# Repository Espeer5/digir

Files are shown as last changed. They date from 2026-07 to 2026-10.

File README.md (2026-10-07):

# DigiR Mobile Digital Mode Transceiver

The DigiR project is an effort to build a fully open source embedded mobile digital mode transciever design for ham operators. Many digital modes tend to require taking a computer running ham software into the field to make connections, which I consider to be a limitation in comparison to analog modes. This project is designed to remove that hurdle by creating a fully embedded platform that enables mobile digital operations.

The full tool chain of the proejct will be open source, avoiding any costly software licenses or other tools out of reach of the average radio hobbyist. An exception to the open-soruce nature of the project are the STM32Cube software packages used for configuring and flashing the STM32 MCU, but these are free packages that are accessible to the hobbyist.

Please note that this project has been significantly delayed due to hardware availability and lead times, which have changed the scope of the project. In particular, the ECP5 development board is very hard to come by at the moment, which is changing the scope of the project. Resulting from this issue some work must now be done to design a custom ECP5 hardware module for development, aside from the eventual custom radio board, increasing both the time and expense required.

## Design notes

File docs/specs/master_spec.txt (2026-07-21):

###################################################################################################
#  DIGIR MASTER PROJECT SPEC
#
#  VERSION 0.1
###################################################################################################

This document defines the system-level requirements for the DigiR open-source amateur radio
platform.

###################################################################################################
#  CHANGE LOG
###################################################################################################

7/17/26  Edward Speer  Initial revision
7/18/26  Edward Speer  Add user control module & rename BPM

###################################################################################################
#  SYSTEM DESCRIPTION
###################################################################################################

DigiR is an open-source, modular digital transceiver designed for standalone mobile amateur radio
operation on digital modes. It consists of a reusable hardware design with extensible enbedded
software, which can be adapted to multiple modes of digital operation. The system is designed to
support education, experimentation, and genuine modern digital radio communications using open
development workflows.

Platform capabilities should include:
 - Self-contained HF digital transceiver operation
 - Mutliple digital communication modes
 - Battery-powered operation
 - Precise GNSS-disciplined timing
 - Open hardware interfaces
 - Open software interfaces
 - Field portability
 - Field firmware & FPGA upgrades 

###################################################################################################
#  TOP-LEVEL BLOCK DIAGRAM
###################################################################################################

                   ______________            ______________________________
                  |              |    5V    |                              |
                  | POWER MODULE |--------->| RF MODULE                    |
                  |              |          |   ___________     _________  |
                   --------------\   12V    |  |           |   |         | |
                         |        \---------|->| POWER AMP |-->| ANTENNA | |
                         | 5V         TX    |  |           |   |         | |
                         v       /--------->|   -----------     ---------  |
                   _____________/           /------------------------------
                  |             |     RX   /      
                  | BASEBAND    |<--------/  _____________________
                  | PROCESSING  |           |                     |
                  | MODULE      |<----------| USER CONTROL MODULE |
                  |             |    SPI    |                     |
                   -------------             ---------------------

###################################################################################################
# PERFORMANCE REQUIREMENTS
###################################################################################################

RF targets:
 - Full amateur general HF coverage (3-30MHz)
 - 96kHz+ ADC instantaneous bandwidth
 - 48kHz+ Usable processed bandwidth
 - 4+ Independently tunable DSP channels
 - 50Hz or less narrowest channels filter
 - 7dB or less receiver noise across supported bands
 - Blocking 60dB at 3kHz, 75dB at 25hHz
 - Minimum discernible signal (MDS) -125 dBm
 - Input damage threshold 10dB or higher
 - 10W+ TX output power

Frequency & Timing:
 - +/- 0.1ppm with GNSS locked
 - +/- 0.1ppm 10 minute holdover
 - +/- 0.5 ppm in freerun
 - Frequency tuning resolution 0.1Hz or less
 - 1us TOD offset, 1ms in holdover
 - 100us TX schedule error, 1ms in holdover

Power Consumption:
 - RX 15W, TX at 30-50W
 - Maximum transient draw: 65W

Required Modes (initial prototype):
 - FT8
 - APRS

###################################################################################################
#  HARDWARE DESCRIPTION
###################################################################################################

The hardware will consist of 3 modules which are connected across clearly documented electrical and
mechanical interfaces. Each module will have its own revision identifier and documentation. The
modules are:
1) Power Module: Responsible for safely charging and discharging the battery and providing properly
                 regulated power to all subsystems.

2) Baseband Processing Module: Resonsible for all messaging logic and the encoding/decoding of
                               symbols to RF.

3) User Control Module: Control surface for users to provide input and configuration, as well as
                        monitor status and operation.

4) RF Module: Responsible for operating the antenna to transmit and receive
              signals over the air.

### POWER MODULE ###

The role of the power module is to provide clean and regulated power to the device. It will support
3 classes of inputs:
1: Internal battery
2: External DC input
3: Charging input

The power module needs to support the following output modes:
1: Baseband processing module regulated supply at 5V, 20W max allocation
2: RF auxiliary supply at 5V, 7.5W max allocation
3: Power amplifier supply at 13.8V, 40W allocation

The power module operates as a state machine with the following states available:
 - Mechanical off/battery disconnect
 - Shipping state (electrically disconnected)
 - Standby
 - EncDec powered only
 - Rx enabled
 - Tx ready
 - Tx active
 - Charging
 - Fault shutdown (E-stop)

The power amplifier supply should be shutoff (reversion to Rx enabled state) when any fault
condition is triggered.

The power module needs to expose status data to the user input module for user monitoring. The
minimum set is:
 - Battery voltage
 - Battery current
 - Ext input voltage
 - Ext input current
 - Rail voltages and currents
 - Battery temperature
 - Charge status
 - Fault state

### BASEBAND PROCESSING MODULE ###

The role of the baseband processing module (BPM) is to provide protocol intelligence, DSP, timing,
logging, and host capabilities. It is the logical brain of the device. There are several subsystems
included.

 ________________________________________________________________________
|                                                    |                   | 
| BASEBAND PROCESSING MODULE                         |                   |
|  __________________                                |                   |
| |                  |                               |                   |
| | DATA CONVERSION  |                               |                   |
| |  _____   _____   |                               |                   |
| | | ADC | | DAC |  |                               |                   |
| |  -----   -----   |                               |                   |
|  ------------------                                |                   |
|  ^^^^^^^^^^^^^^^^^^                                |                   |
|  ||||||||||||||||||                                |                   |
|  vvvvvvvvvvvvvvvvvv                                |                   |
|  __________________     _________________________  |                   |
| |                  |<->|                         | |                   |
| |    PROCESSING    |<->| MEMORY/STORAGE          | |     Protocol      | 
| |  ______   _____  |<->|  _____   _____   _____  | |    Interfaces     |
| | | FPGA | | MCU | |<->| | VOL | | NVM | | USR | | |                   |
| |  ------   -----  |<->|  -----   -----   -----  | |                   |
|  ------------------     -------------------------  |                   |
|  ^^^^^^^^^^^^^^^^^^                                |                   |
|  ||||||||||||||||||                                |                   | 
|  vvvvvvvvvvvvvvvvvv                                |                   |
|  __________________                                |                   |
| |                  |                               |                   |
| | CLOCKS & TIMING  |                               |                   |
| |     ________     |                               |                   |
| |    | VCTCXO |    |                               |                   |
| |     --------     |                               |                   |
| |  ______   _____  |                               |                   |
| | | GNSS | | GEN | |                               |                   |
| |  ------   -----  |                               |                   |
|  ------------------                                |                   |
 ------------------------------------------------------------------------

The NVM holds the bootloader, primary firmware image, and FPGA configuration image, while the
volatile memory is used for runtime data. Some partition of memory is exposed for user data.
Detailed descriptions of each subsystem in the BPM can be found in the detailed docs for the
BPM module.

### USER CONTROL MODULE ###

The user input module consists of the following components, whose functionality is mode dependent
and configurable.
 - Touchscreen: provides display including status & waterfall, and controls including keypad & mode
                selection.
 - PTT switch: available for any phone modes, though the additional target modes do not include
               phone operation.
 - Power Switch
 - 3 rotary knobs: adopt different functions dependent on mode of operation. 

Other than the power switch which is directly in series with the power unit, the other controls
control the baseband processing unit through SPI to the MCU.

### RF MODULE ###

The RF module is composed of a concrete set of components, and is designed to be hot swappable
depending on the desired operating constraints. Components include:
 - Receiver
 - Transmit exciter
 - Power amplifier
 - Frequency synthesis
 - Band filtering
 - T/R switching
 - Measurement
 - Protection
 - Control & telemetry

###################################################################################################
#  SOFTWARE DESCRIPTION
###################################################################################################

The software architecture is both vertically and horizontally divided - horizontally between the
FPGA and the MCU, and vertically up the stack from driver to application level. The vertical layers
are:
1: Device Drivers
2: Hardware Services
3: DSP Services
4: Protocol Layer
5: Application Layer

Differentiated revision identifiers are distributed horizontally, to the FPGA and firmware
separately. 

### FPGA RESPONSIBILITIES ###

 - Streaming DSP
 - Filtering
 - FFT
 - Sample buffering
 - Time recovery
 - Hardware sync
 - DMA support

### FIRMWARE RESPONSIBILITIES ###

 - Radio control
 - Scheduling
 - User interface
 - Communications
 - Protocol implementation
 - Calibration
 - System health monitoring

Protocol implementations will be fully modular and use a standardized interface with the rest of
the system. 

### HOST SOFTWARE RESPONSIBILITIES ###

A number of host software capabilities must be provided to enable hacking on the platform:
 - Firmware updates
 - FPGA programming
 - Diagnostics & logging
 - Factory test
 - Development utils

The software project should have cross-architecture support and not require any proprietary
licensed software.

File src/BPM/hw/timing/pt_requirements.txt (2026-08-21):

###################################################################################################
#  DIGIR BPM CLOCK EVB REQUIREMENTS
#
#  VERSION 0.1
###################################################################################################

The clock EVB is going to be used for protoyping the timing subsystem of the baseband processing
module. Coupled with the MCU, FPGA, and GNSS module, it should constitute a fully GNSS disciplined
clock.

###################################################################################################
#  CHANGE LOG
###################################################################################################

8/15/26  Edward Speer  Initial revision

###################################################################################################
#  INPUTS
###################################################################################################

 - 3V3 external power input
 - System GND
 - Optional ref CLK in (bypasses onboard VCXO)

###################################################################################################
#  OUTPUTS
###################################################################################################

 - Raw VCXO output
 - 2 SMA clocks out from Si5351
 - 1 clock output on a header from Si5351
 - Tuning voltage test point
 - CLKIN test point (differs from VCXO out in bypass mode)
 - Plain 3V3 test point
 - Output clock test points

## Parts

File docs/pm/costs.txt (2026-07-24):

###################################################################################################
#  DIGIR COSTS
###################################################################################################

This document describes all costs curred during the completion of the DigiR project, including test
equipment, licensing, etc. Not all of these costs are necessary for simply building the finished
product, and your mileage may vary. Items are marked with category and whether or not they're
required for the minimal build. 
 _________________________________________________________________________________________________
| ITEM | COST | CATEGORY  | REQUIRED? | SOURCE |
|---|---|---|---|---|
| FCC amateur license | $49 | Licensing | yes | Local testing organization, FCC. |
|-------------------------|---------|-----------|-----------|-------------------------------------|
| STM32H745I-DISCO | $154.78 | Bring up  | no | ST-direct |
|-------------------------|---------|-----------|-----------|-------------------------------------|
| KA3005P | $155.00 | Testing | no | Amazon |
|-------------------------|---------|-----------|-----------|-------------------------------------|
| ESD tweezers | $5.99 | Bench | no | Amazon |
|-------------------------|---------|-----------|-----------|-------------------------------------|
| ESD mat, bracelet | $20.99  | Bench | no | Amazon |
|-------------------------|---------|-----------|-----------|-------------------------------------|
| HiLetgo logic analyer | $12.69  | Test | no | Amazon |
|-------------------------------------------------------------------------------------------------|
| TOTAL: $358.78 |
|-------------------------------------------------------------------------------------------------|
| REQUIRED: $49 |
 -------------------------------------------------------------------------------------------------

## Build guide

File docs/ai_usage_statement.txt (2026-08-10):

###################################################################################################
#  DIGIR AI USAGE STATEMENT
#
#  VERSION 0.1
###################################################################################################

This document describes the ways in which AI has and has not been used in the completion of the
digiR project.

###################################################################################################
#  USAGE STATEMENT
###################################################################################################

Some of the primary objectives of this project include education and reproducability. AI can be an
extremely powerful tool for assisting these objectives, but only when interacted with in specific
ways. For example, asking an LLM to explain a certain concept or technical requirement can be much
more effective than a web search. The ability to ask follow-up questions in particular can replace
a lot of manual research and allow rapid learning. However, not all uses of AI achieve this goal -
in particular asking an agent to design a subsystem or write the code can bypass the learning
process altogether. It is of course, still possible to learn this way when time and care is taken
to understand the outputs, but I personally feel that I don't learn as well this way as I do in the
process of manually producing the components. For this reason I have developed a brief set of
guidelines that describe the guardrails I will apply to the use of AI in this project. When working
with this project, feel free to use AI however you like to your heart's content -- these are merely
my own guardrails to hold myself to in order to promote my own learning and objectives.

### GUARDRAILS ###

1: Chat mode only

One major point of emphasis for this project is that I learn best by doing, and I want to manually
write the code and create the schematics. For this reason I don't want to set agents loose into the
workspace to go and build things for me.

2: No debugging

AI is very good at debugging, but doing it manually is satisfying to me and helps me avoid making
repeat mistakes in the future. I also intend to work with some unfamiliar languages during the
course of the project and learning the syntax rather than asking an LLM to fix it is very valuable
for language mastery.

3: Always ask for sources

Not because I don't believe the AI outputs are accurate -- they typically are. Instead, I want to
know what sources should be consulted to find the answers to the questions I have. Also, I'm doing
this project because I'm interested in the project topic, and I suspect that the sources the LLM
cites will prove interesting enough to read through, providing additional learning.

4: Log interactions

It may be valuable or interesting for those following this project to see how AI has been used in
different phases of the project. After consulting with AI, record brief logs of how it was used and
what was learned in the process for transparency to others. Logs will be kept below in this
document.

###################################################################################################
#  USAGE LOGS
###################################################################################################
 _________________________________________________________________________________________________
| DATE | MODEL | USE CASE | NOTES |
|---|---|---|---|
| 07/18/26 | GPT 5.6 | Technical specs for RF module | Primary source cited and used for spec dev |
| | | to support digital modes | was the WSJT-X protocol specification. |
|----------|---------|-------------------------------|--------------------------------------------|
| 07/20/26 | GPT 5.6 | Scraping web for dev kits to  | Due to memory shortage everything is |
| | | purchase at reasonable prices | pricy, and AI didn't really help. |
|----------|---------|-------------------------------|--------------------------------------------|
| 07/23/26 | GPT 5.6 | Use of open source tools for  | Pointed me directly to |
| | | synthesizing/flashing ECP5 | jjhorton.co.uk/posts/ecp5g-eval/ which |
| | | hardware. | provided all the answers I needed. |
|----------|---------|-------------------------------|--------------------------------------------|
| 07/24/26 | GPT 5.6 | Table-based testbench inSV. | Provided a great pattern, but it isn't |
| | | | supported by Icarus. Gave me a different |
| | | | way of doing it that I don't really like.  |
|----------|---------|-------------------------------|--------------------------------------------|
| 07/25/26 | GPT 5.6 | Discussion of general design  | Referred to generic documents about PI |
| | | of time servo. | control that were too basic, but provided  |
| | | | useful guidance on fixed-point usage. |
|----------|---------|-------------------------------|--------------------------------------------|
| 07/27/26 | GPT 5.6 | Toolchain setup for STM32 FW  | Yes, I used it for some CMake debugging. |
| | | | Yes, that's slightly against the policy. |
| | | | But now everything builds and I'm happy. |
|----------|---------|-------------------------------|--------------------------------------------|
| 07/29/26 | GPT 5.6 | STM32 interrupt handlers | I didn't really want to dig through the |
| | | | generated code to see how to capture and |
| | | | handle UART interrupts. GPT was able to |
| | | | tell me where the code was easily. |
|----------|---------|-------------------------------|--------------------------------------------|
| 07/30/36 | GPT 5.5 | NMEA format/protocol | GPT pointed me to |
| | | | https://gpsd.gitlab.io/gpsd/NMEA.html |
|----------|---------|-------------------------------|--------------------------------------------|
| 07/31/26 | GPT 5.6 | Syntax for writing to UART3 | Yeah I could've check the HAL docs but how |
| | | | much would that really have taught me? |
|----------|---------|-------------------------------|--------------------------------------------|
| 08/02/26 | GPT 5.6 | Use of PulseView for logic | Needed instructions on which model to |
| | | analyzer model. | select in the menu since my analyzer is |
| | | | unmarked. |
|----------|---------|-------------------------------|--------------------------------------------|
| 08/10/26 | GPT 5.6 | Functional gaps with HW NSS | STM32 HW NSS usage is apparently very |
| | | | limiting to what you can do with your FPGA |
| | | | on the other side. Glad GPT warned me. |
 -------------------------------------------------------------------------------------------------

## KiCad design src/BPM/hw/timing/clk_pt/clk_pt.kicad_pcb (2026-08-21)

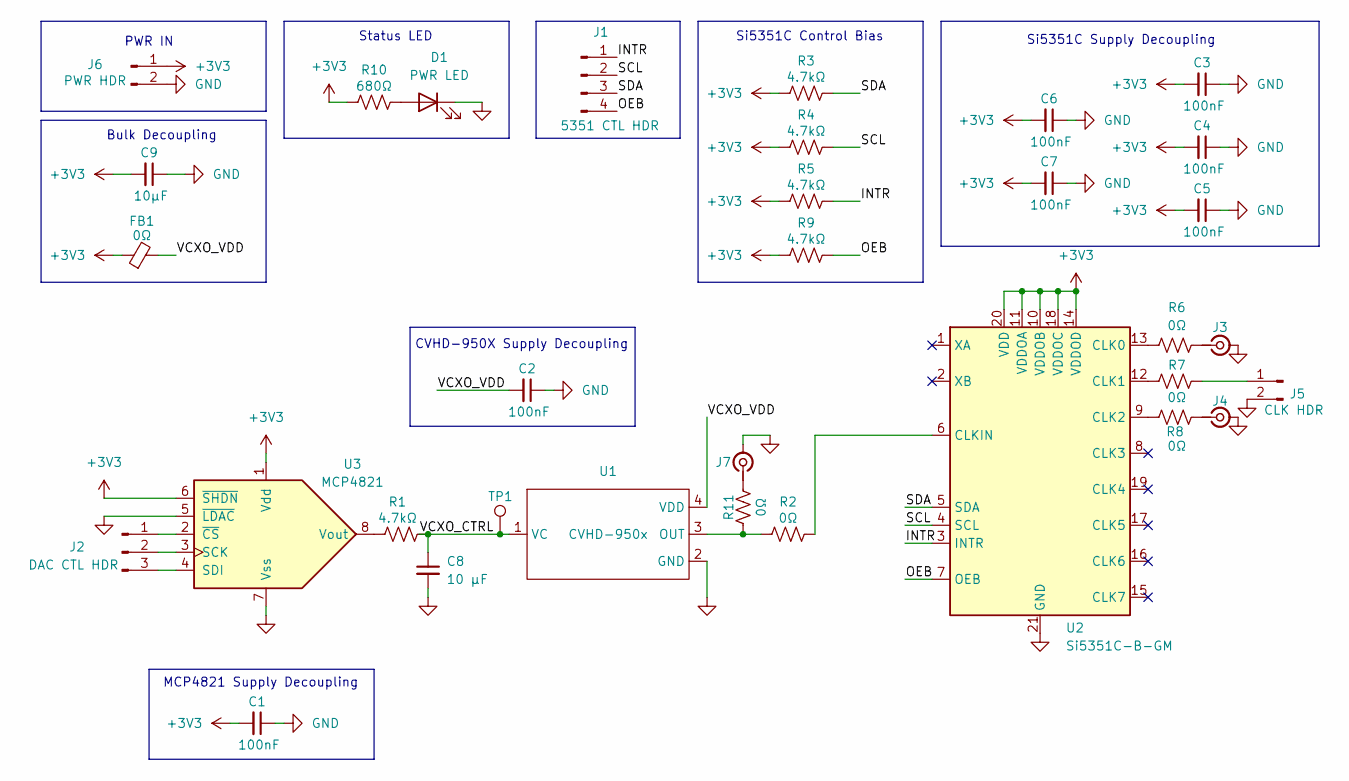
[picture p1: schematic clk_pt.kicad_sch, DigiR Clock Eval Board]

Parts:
C1, C2, C3, C4, C5, C6, C7: 100nF; C_0603_1608Metric
C8: 10 µF; C_0805_2012Metric
C9: 10µF; C_0805_2012Metric
D1: PWR LED; LED_0805_2012Metric
FB1: 0Ω; R_0603_1608Metric
J1: 5351 CTL HDR; PinHeader_1x04_P2.54mm_Vertical
J2: DAC CTL HDR; PinHeader_1x03_P2.54mm_Vertical
J3, J4, J7: SMA_Molex_73251-1153_EdgeMount_Horizontal
J5: CLK HDR; PinHeader_1x02_P2.54mm_Vertical
J6: PWR HDR; PinHeader_1x02_P2.54mm_Vertical
R1, R3, R4, R5, R9: 4.7kΩ; R_0603_1608Metric
R2, R6, R7, R8, R11: 0Ω; R_0603_1608Metric
R10: 680Ω; R_0603_1608Metric
TP1: TestPoint; TestPoint_THTPad_D2.0mm_Drill1.0mm
U1: CVHD-950x; OSC_CVHD-950X-100
U2: Si5351C-B-GM; QFN-20-1EP_4x4mm_P0.5mm_EP2.7x2.7mm
U3: MCP4821; SOIC-8_3.9x4.9mm_P1.27mm

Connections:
+3V3: C1.2, C3.2, C4.2, C5.2, C6.2, C7.2, C9.2, FB1.1, J6.1, R3.1, R4.1, R5.1, R9.1, R10.1, U2.10 (VDDOB), U2.11 (VDDOA), U2.14 (VDDOD), U2.18 (VDDOC), U2.20 (VDD), U3.1 (Vdd), U3.6 (~SHDN)
/INTR: J1.1, R5.2, U2.3 (INTR)
/OEB: J1.4, R9.2, U2.7 (OEB)
/SCL: J1.2, R4.2, U2.4 (SCL)
/SDA: J1.3, R3.2, U2.5 (SDA)
/VCXO_CTRL: C8.1, R1.2, TP1.1 (1_1), U1.1 (VC)
/VCXO_VDD: C2.2, FB1.2, U1.4 (VDD)
GND: C1.1, C2.1, C3.1, C4.1, C5.1, C6.1, C7.1, C8.2, C9.1, D1.1 (K), J3.2 (Ext), J4.2 (Ext), J5.2, J6.2, J7.2 (Ext), U1.2 (GND), U2.21 (GND), U3.5 (~LDAC), U3.7 (Vss)
unnamed: D1.2 (A), R10.2
unnamed: J2.1, U3.2 (~CS)
unnamed: J2.2, U3.3 (SCK)
unnamed: J2.3, U3.4 (SDI)
unnamed: J3.1 (In), R6.2
unnamed: J4.1 (In), R8.2
unnamed: J5.1, R7.2
unnamed: J7.1 (In), R11.2
unnamed: R2.1, R11.1, U1.3 (OUT)
unnamed: R6.1, U2.13 (CLK0)
unnamed: R7.1, U2.12 (CLK1)
unnamed: R8.1, U2.9 (CLK2)
unnamed: R2.2, U2.6 (CLKIN)
unnamed: R1.1, U3.8 (Vout)

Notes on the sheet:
CVHD-950X Supply Decoupling
Status LED
Si5351C Supply Decoupling
Bulk Decoupling
MCP4821 Supply Decoupling
Si5351C Control Bias
PWR IN

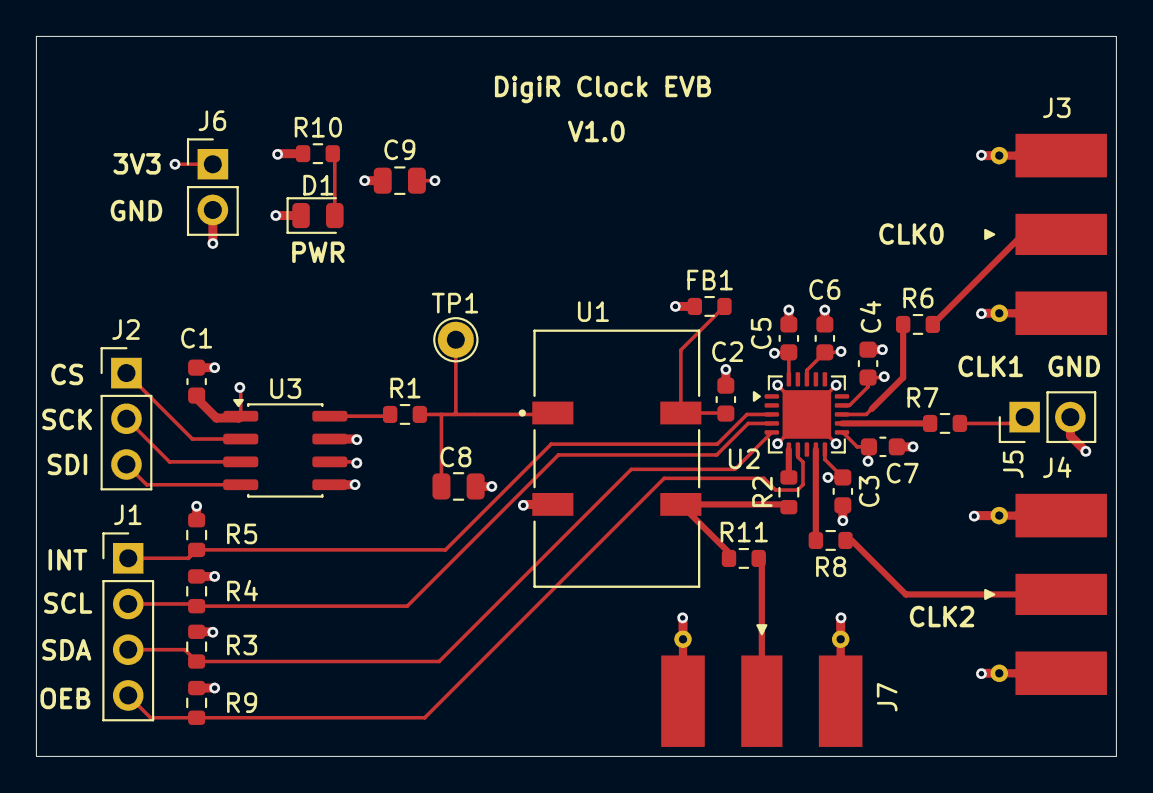
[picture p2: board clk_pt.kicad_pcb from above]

Board: 4 copper layers, 60.0 x 40.0 mm, 33 parts (0 on the bottom side), 22 nets.

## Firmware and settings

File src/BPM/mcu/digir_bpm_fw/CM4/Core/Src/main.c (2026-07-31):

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
/* Includes ------------------------------------------------------------------*/
#include "main.h"
#include "string.h"

/* USER CODE BEGIN PD */

/* DUAL_CORE_BOOT_SYNC_SEQUENCE: Define for dual core boot synchronization    */
/*                             demonstration code based on hardware semaphore */
/* This define is present in both CM7/CM4 projects                            */
/* To comment when developping/debugging on a single core                     */
#define DUAL_CORE_BOOT_SYNC_SEQUENCE

#if defined(DUAL_CORE_BOOT_SYNC_SEQUENCE)
#ifndef HSEM_ID_0
#define HSEM_ID_0 (0U) /* HW semaphore 0*/
#endif
#endif /* DUAL_CORE_BOOT_SYNC_SEQUENCE */

/* USER CODE END PD */

#if defined ( __ICCARM__ ) /*!< IAR Compiler */
#pragma location=0x10040000
ETH_DMADescTypeDef  DMARxDscrTab[ETH_RX_DESC_CNT]; /* Ethernet Rx DMA Descriptors */
#pragma location=0x10040080
ETH_DMADescTypeDef  DMATxDscrTab[ETH_TX_DESC_CNT]; /* Ethernet Tx DMA Descriptors */

#elif defined ( __CC_ARM )  /* MDK ARM Compiler */

__attribute__((at(0x10040000))) ETH_DMADescTypeDef  DMARxDscrTab[ETH_RX_DESC_CNT]; /* Ethernet Rx DMA Descriptors */
__attribute__((at(0x10040080))) ETH_DMADescTypeDef  DMATxDscrTab[ETH_TX_DESC_CNT]; /* Ethernet Tx DMA Descriptors */

#elif defined ( __GNUC__ ) /* GNU Compiler */

ETH_DMADescTypeDef DMARxDscrTab[ETH_RX_DESC_CNT] __attribute__((section(".RxDescripSection"))); /* Ethernet Rx DMA Descriptors */
ETH_DMADescTypeDef DMATxDscrTab[ETH_TX_DESC_CNT] __attribute__((section(".TxDescripSection")));   /* Ethernet Tx DMA Descriptors */
#endif

ETH_TxPacketConfig TxConfig;

ETH_HandleTypeDef heth;

FDCAN_HandleTypeDef hfdcan1;
FDCAN_HandleTypeDef hfdcan2;

LTDC_HandleTypeDef hltdc;

QSPI_HandleTypeDef hqspi;

SAI_HandleTypeDef hsai_BlockA2;
SAI_HandleTypeDef hsai_BlockB2;

MMC_HandleTypeDef hmmc1;

PCD_HandleTypeDef hpcd_USB_OTG_FS;

SDRAM_HandleTypeDef hsdram1;

static void MX_GPIO_Init(void);
static void MX_ETH_Init(void);
static void MX_FDCAN1_Init(void);
static void MX_FDCAN2_Init(void);
static void MX_FMC_Init(void);
static void MX_LTDC_Init(void);
static void MX_QUADSPI_Init(void);
static void MX_SAI2_Init(void);
static void MX_SDMMC1_MMC_Init(void);
static void MX_USB_OTG_FS_PCD_Init(void);
/**
  * @brief  The application entry point.
  * @retval int
  */
int main(void)
{

/* USER CODE BEGIN Boot_Mode_Sequence_1 */
#if defined(DUAL_CORE_BOOT_SYNC_SEQUENCE)
  /*HW semaphore Clock enable*/
  __HAL_RCC_HSEM_CLK_ENABLE();
  /* Activate HSEM notification for Cortex-M4*/
  HAL_HSEM_ActivateNotification(__HAL_HSEM_SEMID_TO_MASK(HSEM_ID_0));
  /*
  Domain D2 goes to STOP mode (Cortex-M4 in deep-sleep) waiting for Cortex-M7 to
  perform system initialization (system clock config, external memory configuration.. )
  */
  HAL_PWREx_ClearPendingEvent();
  HAL_PWREx_EnterSTOPMode(PWR_MAINREGULATOR_ON, PWR_STOPENTRY_WFE, PWR_D2_DOMAIN);
  /* Clear HSEM flag */
  __HAL_HSEM_CLEAR_FLAG(__HAL_HSEM_SEMID_TO_MASK(HSEM_ID_0));

#endif /* DUAL_CORE_BOOT_SYNC_SEQUENCE */
/* USER CODE END Boot_Mode_Sequence_1 */
  /* MCU Configuration--------------------------------------------------------*/

  /* Reset of all peripherals, Initializes the Flash interface and the Systick. */
  HAL_Init();

  /* Initialize all configured peripherals */
  MX_GPIO_Init();
  MX_ETH_Init();
  MX_FDCAN1_Init();
  MX_FDCAN2_Init();
  MX_FMC_Init();
  MX_LTDC_Init();
  MX_QUADSPI_Init();
  MX_SAI2_Init();
  MX_SDMMC1_MMC_Init();
  MX_USB_OTG_FS_PCD_Init();
  /* Infinite loop */
  /* USER CODE BEGIN WHILE */
  while (1)
  {
    /* USER CODE END WHILE */

    /* USER CODE BEGIN 3 */
  }
  /* USER CODE END 3 */
}

/**
  * @brief ETH Initialization Function
  * @param None
  * @retval None
  */
static void MX_ETH_Init(void)
{

   static uint8_t MACAddr[6];

  heth.Instance = ETH;
  MACAddr[0] = 0x00;
  MACAddr[1] = 0x80;
  MACAddr[2] = 0xE1;
  MACAddr[3] = 0x00;
  MACAddr[4] = 0x00;
  MACAddr[5] = 0x00;
  heth.Init.MACAddr = &MACAddr[0];
  heth.Init.MediaInterface = HAL_ETH_MII_MODE;
  heth.Init.TxDesc = DMATxDscrTab;
  heth.Init.RxDesc = DMARxDscrTab;
  heth.Init.RxBuffLen = 1536;

  if (HAL_ETH_Init(&heth) != HAL_OK)
  {
    Error_Handler();
  }

  memset(&TxConfig, 0 , sizeof(ETH_TxPacketConfig));
  TxConfig.Attributes = ETH_TX_PACKETS_FEATURES_CSUM | ETH_TX_PACKETS_FEATURES_CRCPAD;
  TxConfig.ChecksumCtrl = ETH_CHECKSUM_IPHDR_PAYLOAD_INSERT_PHDR_CALC;
  TxConfig.CRCPadCtrl = ETH_CRC_PAD_INSERT;
}

/**
  * @brief FDCAN1 Initialization Function
  * @param None
  * @retval None
  */
static void MX_FDCAN1_Init(void)
{

  hfdcan1.Instance = FDCAN1;
  hfdcan1.Init.FrameFormat = FDCAN_FRAME_CLASSIC;
  hfdcan1.Init.Mode = FDCAN_MODE_NORMAL;
  hfdcan1.Init.AutoRetransmission = DISABLE;
  hfdcan1.Init.TransmitPause = DISABLE;
  hfdcan1.Init.ProtocolException = DISABLE;
  hfdcan1.Init.NominalPrescaler = 16;
  hfdcan1.Init.NominalSyncJumpWidth = 1;
  hfdcan1.Init.NominalTimeSeg1 = 1;
  hfdcan1.Init.NominalTimeSeg2 = 1;
  hfdcan1.Init.DataPrescaler = 1;
  hfdcan1.Init.DataSyncJumpWidth = 1;
  hfdcan1.Init.DataTimeSeg1 = 1;
  hfdcan1.Init.DataTimeSeg2 = 1;
  hfdcan1.Init.MessageRAMOffset = 0;
  hfdcan1.Init.StdFiltersNbr = 0;
  hfdcan1.Init.ExtFiltersNbr = 0;
  hfdcan1.Init.RxFifo0ElmtsNbr = 0;
  hfdcan1.Init.RxFifo0ElmtSize = FDCAN_DATA_BYTES_8;
  hfdcan1.Init.RxFifo1ElmtsNbr = 0;
  hfdcan1.Init.RxFifo1ElmtSize = FDCAN_DATA_BYTES_8;
  hfdcan1.Init.RxBuffersNbr = 0;
  hfdcan1.Init.RxBufferSize = FDCAN_DATA_BYTES_8;
  hfdcan1.Init.TxEventsNbr = 0;
  hfdcan1.Init.TxBuffersNbr = 0;
  hfdcan1.Init.TxFifoQueueElmtsNbr = 0;
  hfdcan1.Init.TxFifoQueueMode = FDCAN_TX_FIFO_OPERATION;
  hfdcan1.Init.TxElmtSize = FDCAN_DATA_BYTES_8;
  if (HAL_FDCAN_Init(&hfdcan1) != HAL_OK)
  {
    Error_Handler();
  }
}

/**
  * @brief FDCAN2 Initialization Function
  * @param None
  * @retval None
  */
static void MX_FDCAN2_Init(void)
{

  hfdcan2.Instance = FDCAN2;
  hfdcan2.Init.FrameFormat = FDCAN_FRAME_CLASSIC;
  hfdcan2.Init.Mode = FDCAN_MODE_NORMAL;
  hfdcan2.Init.AutoRetransmission = DISABLE;
  hfdcan2.Init.TransmitPause = DISABLE;
  hfdcan2.Init.ProtocolException = DISABLE;
  hfdcan2.Init.NominalPrescaler = 16;
  hfdcan2.Init.NominalSyncJumpWidth = 1;
  hfdcan2.Init.NominalTimeSeg1 = 1;
  hfdcan2.Init.NominalTimeSeg2 = 1;
  hfdcan2.Init.DataPrescaler = 1;
  hfdcan2.Init.DataSyncJumpWidth = 1;
  hfdcan2.Init.DataTimeSeg1 = 1;
  hfdcan2.Init.DataTimeSeg2 = 1;
  hfdcan2.Init.MessageRAMOffset = 0;
  hfdcan2.Init.StdFiltersNbr = 0;
  hfdcan2.Init.ExtFiltersNbr = 0;
  hfdcan2.Init.RxFifo0ElmtsNbr = 0;
  hfdcan2.Init.RxFifo0ElmtSize = FDCAN_DATA_BYTES_8;
  hfdcan2.Init.RxFifo1ElmtsNbr = 0;
  hfdcan2.Init.RxFifo1ElmtSize = FDCAN_DATA_BYTES_8;
  hfdcan2.Init.RxBuffersNbr = 0;
  hfdcan2.Init.RxBufferSize = FDCAN_DATA_BYTES_8;
  hfdcan2.Init.TxEventsNbr = 0;
  hfdcan2.Init.TxBuffersNbr = 0;
  hfdcan2.Init.TxFifoQueueElmtsNbr = 0;
  hfdcan2.Init.TxFifoQueueMode = FDCAN_TX_FIFO_OPERATION;
  hfdcan2.Init.TxElmtSize = FDCAN_DATA_BYTES_8;
  if (HAL_FDCAN_Init(&hfdcan2) != HAL_OK)
  {
    Error_Handler();
  }
}

/**
  * @brief LTDC Initialization Function
  * @param None
  * @retval None
  */
static void MX_LTDC_Init(void)
{

  LTDC_LayerCfgTypeDef pLayerCfg = {0};
  LTDC_LayerCfgTypeDef pLayerCfg1 = {0};

  hltdc.Instance = LTDC;
  hltdc.Init.HSPolarity = LTDC_HSPOLARITY_AL;
  hltdc.Init.VSPolarity = LTDC_VSPOLARITY_AL;
  hltdc.Init.DEPolarity = LTDC_DEPOLARITY_AL;
  hltdc.Init.PCPolarity = LTDC_PCPOLARITY_IPC;
  hltdc.Init.HorizontalSync = 7;
  hltdc.Init.VerticalSync = 3;
  hltdc.Init.AccumulatedHBP = 14;
  hltdc.Init.AccumulatedVBP = 5;
  hltdc.Init.AccumulatedActiveW = 654;
  hltdc.Init.AccumulatedActiveH = 485;
  hltdc.Init.TotalWidth = 660;
  hltdc.Init.TotalHeigh = 487;
  hltdc.Init.Backcolor.Blue = 0;
  hltdc.Init.Backcolor.Green = 0;
  hltdc.Init.Backcolor.Red = 0;
  if (HAL_LTDC_Init(&hltdc) != HAL_OK)
  {
    Error_Handler();
  }
  pLayerCfg.WindowX0 = 0;
  pLayerCfg.WindowX1 = 0;
  pLayerCfg.WindowY0 = 0;
  pLayerCfg.WindowY1 = 0;
  pLayerCfg.PixelFormat = LTDC_PIXEL_FORMAT_ARGB8888;
  pLayerCfg.Alpha = 0;
  pLayerCfg.Alpha0 = 0;
  pLayerCfg.BlendingFactor1 = LTDC_BLENDING_FACTOR1_CA;
  pLayerCfg.BlendingFactor2 = LTDC_BLENDING_FACTOR2_CA;
  pLayerCfg.FBStartAdress = 0;
  pLayerCfg.ImageWidth = 0;
  pLayerCfg.ImageHeight = 0;
  pLayerCfg.Backcolor.Blue = 0;
  pLayerCfg.Backcolor.Green = 0;
  pLayerCfg.Backcolor.Red = 0;
  if (HAL_LTDC_ConfigLayer(&hltdc, &pLayerCfg, 0) != HAL_OK)
  {
    Error_Handler();
  }
  pLayerCfg1.WindowX0 = 0;
  pLayerCfg1.WindowX1 = 0;
  pLayerCfg1.WindowY0 = 0;
  pLayerCfg1.WindowY1 = 0;
  pLayerCfg1.PixelFormat = LTDC_PIXEL_FORMAT_ARGB8888;
  pLayerCfg1.Alpha = 0;
  pLayerCfg1.Alpha0 = 0;
  pLayerCfg1.BlendingFactor1 = LTDC_BLENDING_FACTOR1_CA;
  pLayerCfg1.BlendingFactor2 = LTDC_BLENDING_FACTOR2_CA;
  pLayerCfg1.FBStartAdress = 0;
  pLayerCfg1.ImageWidth = 0;
  pLayerCfg1.ImageHeight = 0;
  pLayerCfg1.Backcolor.Blue = 0;
  pLayerCfg1.Backcolor.Green = 0;
  pLayerCfg1.Backcolor.Red = 0;
  if (HAL_LTDC_ConfigLayer(&hltdc, &pLayerCfg1, 1) != HAL_OK)
  {
    Error_Handler();
  }
}

/**
  * @brief QUADSPI Initialization Function
  * @param None
  * @retval None
  */
static void MX_QUADSPI_Init(void)
{

  /* QUADSPI parameter configuration*/
  hqspi.Instance = QUADSPI;
  hqspi.Init.ClockPrescaler = 255;
  hqspi.Init.FifoThreshold = 1;
  hqspi.Init.SampleShifting = QSPI_SAMPLE_SHIFTING_NONE;
  hqspi.Init.FlashSize = 1;
  hqspi.Init.ChipSelectHighTime = QSPI_CS_HIGH_TIME_1_CYCLE;
  hqspi.Init.ClockMode = QSPI_CLOCK_MODE_0;
  hqspi.Init.FlashID = QSPI_FLASH_ID_1;
  hqspi.Init.DualFlash = QSPI_DUALFLASH_DISABLE;
  if (HAL_QSPI_Init(&hqspi) != HAL_OK)
  {
    Error_Handler();
  }
}

/**
  * @brief SAI2 Initialization Function
  * @param None
  * @retval None
  */
static void MX_SAI2_Init(void)
{

  hsai_BlockA2.Instance = SAI2_Block_A;
  hsai_BlockA2.Init.Protocol = SAI_FREE_PROTOCOL;
  hsai_BlockA2.Init.AudioMode = SAI_MODEMASTER_TX;
  hsai_BlockA2.Init.DataSize = SAI_DATASIZE_8;
  hsai_BlockA2.Init.FirstBit = SAI_FIRSTBIT_MSB;
  hsai_BlockA2.Init.ClockStrobing = SAI_CLOCKSTROBING_FALLINGEDGE;
  hsai_BlockA2.Init.Synchro = SAI_ASYNCHRONOUS;
  hsai_BlockA2.Init.OutputDrive = SAI_OUTPUTDRIVE_DISABLE;
  hsai_BlockA2.Init.NoDivider = SAI_MASTERDIVIDER_ENABLE;
  hsai_BlockA2.Init.MckOverSampling = SAI_MCK_OVERSAMPLING_DISABLE;
  hsai_BlockA2.Init.FIFOThreshold = SAI_FIFOTHRESHOLD_EMPTY;
  hsai_BlockA2.Init.AudioFrequency = SAI_AUDIO_FREQUENCY_192K;
  hsai_BlockA2.Init.SynchroExt = SAI_SYNCEXT_DISABLE;
  hsai_BlockA2.Init.MonoStereoMode = SAI_STEREOMODE;
  hsai_BlockA2.Init.CompandingMode = SAI_NOCOMPANDING;
  hsai_BlockA2.Init.TriState = SAI_OUTPUT_NOTRELEASED;
  hsai_BlockA2.Init.PdmInit.Activation = DISABLE;
  hsai_BlockA2.Init.PdmInit.MicPairsNbr = 1;
  hsai_BlockA2.Init.PdmInit.ClockEnable = SAI_PDM_CLOCK1_ENABLE;
  hsai_BlockA2.FrameInit.FrameLength = 8;
  hsai_BlockA2.FrameInit.ActiveFrameLength = 1;
  hsai_BlockA2.FrameInit.FSDefinition = SAI_FS_STARTFRAME;
  hsai_BlockA2.FrameInit.FSPolarity = SAI_FS_ACTIVE_LOW;
  hsai_BlockA2.FrameInit.FSOffset = SAI_FS_FIRSTBIT;
  hsai_BlockA2.SlotInit.FirstBitOffset = 0;
  hsai_BlockA2.SlotInit.SlotSize = SAI_SLOTSIZE_DATASIZE;
  hsai_BlockA2.SlotInit.SlotNumber = 1;
  hsai_BlockA2.SlotInit.SlotActive = 0x00000000;
  if (HAL_SAI_Init(&hsai_BlockA2) != HAL_OK)
  {
    Error_Handler();
  }
  hsai_BlockB2.Instance = SAI2_Block_B;
  hsai_BlockB2.Init.Protocol = SAI_FREE_PROTOCOL;
  hsai_BlockB2.Init.AudioMode = SAI_MODESLAVE_RX;
  hsai_BlockB2.Init.DataSize = SAI_DATASIZE_8;
  hsai_BlockB2.Init.FirstBit = SAI_FIRSTBIT_MSB;
  hsai_BlockB2.Init.ClockStrobing = SAI_CLOCKSTROBING_FALLINGEDGE;
  hsai_BlockB2.Init.Synchro = SAI_SYNCHRONOUS;
  hsai_BlockB2.Init.OutputDrive = SAI_OUTPUTDRIVE_DISABLE;
  hsai_BlockB2.Init.MckOverSampling = SAI_MCK_OVERSAMPLING_DISABLE;
  hsai_BlockB2.Init.FIFOThreshold = SAI_FIFOTHRESHOLD_EMPTY;
  hsai_BlockB2.Init.SynchroExt = SAI_SYNCEXT_DISABLE;
  hsai_BlockB2.Init.MonoStereoMode = SAI_STEREOMODE;
  hsai_BlockB2.Init.CompandingMode = SAI_NOCOMPANDING;
  hsai_BlockB2.Init.TriState = SAI_OUTPUT_NOTRELEASED;
  hsai_BlockB2.Init.PdmInit.Activation = DISABLE;
  hsai_BlockB2.Init.PdmInit.MicPairsNbr = 1;
  hsai_BlockB2.Init.PdmInit.ClockEnable = SAI_PDM_CLOCK1_ENABLE;
  hsai_BlockB2.FrameInit.FrameLength = 8;
  hsai_BlockB2.FrameInit.ActiveFrameLength = 1;
  hsai_BlockB2.FrameInit.FSDefinition = SAI_FS_STARTFRAME;
  hsai_BlockB2.FrameInit.FSPolarity = SAI_FS_ACTIVE_LOW;
  hsai_BlockB2.FrameInit.FSOffset = SAI_FS_FIRSTBIT;
  hsai_BlockB2.SlotInit.FirstBitOffset = 0;
  hsai_BlockB2.SlotInit.SlotSize = SAI_SLOTSIZE_DATASIZE;
  hsai_BlockB2.SlotInit.SlotNumber = 1;
  hsai_BlockB2.SlotInit.SlotActive = 0x00000000;
  if (HAL_SAI_Init(&hsai_BlockB2) != HAL_OK)
  {
    Error_Handler();
  }
}

/**
  * @brief SDMMC1 Initialization Function
  * @param None
  * @retval None
  */
static void MX_SDMMC1_MMC_Init(void)
{

  hmmc1.Instance = SDMMC1;
  hmmc1.Init.ClockEdge = SDMMC_CLOCK_EDGE_RISING;
  hmmc1.Init.ClockPowerSave = SDMMC_CLOCK_POWER_SAVE_DISABLE;
  hmmc1.Init.BusWide = SDMMC_BUS_WIDE_8B;
  hmmc1.Init.HardwareFlowControl = SDMMC_HARDWARE_FLOW_CONTROL_DISABLE;
  hmmc1.Init.ClockDiv = 0;
  if (HAL_MMC_Init(&hmmc1) != HAL_OK)
  {
    Error_Handler();
  }
}

/**
  * @brief USB_OTG_FS Initialization Function
  * @param None
  * @retval None
  */
static void MX_USB_OTG_FS_PCD_Init(void)
{

  hpcd_USB_OTG_FS.Instance = USB_OTG_FS;
  hpcd_USB_OTG_FS.Init.dev_endpoints = 9;
  hpcd_USB_OTG_FS.Init.speed = PCD_SPEED_FULL;
  hpcd_USB_OTG_FS.Init.dma_enable = DISABLE;
  hpcd_USB_OTG_FS.Init.phy_itface = PCD_PHY_EMBEDDED;
  hpcd_USB_OTG_FS.Init.Sof_enable = DISABLE;
  hpcd_USB_OTG_FS.Init.low_power_enable = DISABLE;
  hpcd_USB_OTG_FS.Init.lpm_enable = DISABLE;
  hpcd_USB_OTG_FS.Init.battery_charging_enable = ENABLE;
  hpcd_USB_OTG_FS.Init.vbus_sensing_enable = ENABLE;
  hpcd_USB_OTG_FS.Init.use_dedicated_ep1 = DISABLE;
  if (HAL_PCD_Init(&hpcd_USB_OTG_FS) != HAL_OK)
  {
    Error_Handler();
  }
}

/* FMC initialization function */
void MX_FMC_Init(void)
{

  FMC_SDRAM_TimingTypeDef SdramTiming = {0};

  /** Perform the SDRAM1 memory initialization sequence
  */
  hsdram1.Instance = FMC_SDRAM_DEVICE;
  /* hsdram1.Init */
  hsdram1.Init.SDBank = FMC_SDRAM_BANK2;
  hsdram1.Init.ColumnBitsNumber = FMC_SDRAM_COLUMN_BITS_NUM_8;
  hsdram1.Init.RowBitsNumber = FMC_SDRAM_ROW_BITS_NUM_12;
  hsdram1.Init.MemoryDataWidth = FMC_SDRAM_MEM_BUS_WIDTH_16;
  hsdram1.Init.InternalBankNumber = FMC_SDRAM_INTERN_BANKS_NUM_4;
  hsdram1.Init.CASLatency = FMC_SDRAM_CAS_LATENCY_1;
  hsdram1.Init.WriteProtection = FMC_SDRAM_WRITE_PROTECTION_DISABLE;
  hsdram1.Init.SDClockPeriod = FMC_SDRAM_CLOCK_DISABLE;
  hsdram1.Init.ReadBurst = FMC_SDRAM_RBURST_DISABLE;
  hsdram1.Init.ReadPipeDelay = FMC_SDRAM_RPIPE_DELAY_0;
  /* SdramTiming */
  SdramTiming.LoadToActiveDelay = 16;
  SdramTiming.ExitSelfRefreshDelay = 16;
  SdramTiming.SelfRefreshTime = 16;
  SdramTiming.RowCycleDelay = 16;
  SdramTiming.WriteRecoveryTime = 16;
  SdramTiming.RPDelay = 16;
  SdramTiming.RCDDelay = 16;

  if (HAL_SDRAM_Init(&hsdram1, &SdramTiming) != HAL_OK)
  {
    Error_Handler( );
  }

}

/**
  * @brief GPIO Initialization Function
  * @param None
  * @retval None
  */
static void MX_GPIO_Init(void)
{
  GPIO_InitTypeDef GPIO_InitStruct = {0};
  /* GPIO Ports Clock Enable */
  __HAL_RCC_GPIOI_CLK_ENABLE();
  __HAL_RCC_GPIOB_CLK_ENABLE();
  __HAL_RCC_GPIOK_CLK_ENABLE();
  __HAL_RCC_GPIOG_CLK_ENABLE();
  __HAL_RCC_GPIOC_CLK_ENABLE();
  __HAL_RCC_GPIOE_CLK_ENABLE();
  __HAL_RCC_GPIOJ_CLK_ENABLE();
  __HAL_RCC_GPIOH_CLK_ENABLE();
  __HAL_RCC_GPIOD_CLK_ENABLE();
  __HAL_RCC_GPIOA_CLK_ENABLE();
  __HAL_RCC_GPIOF_CLK_ENABLE();

  /*Configure GPIO pins : PE5 PE4 */
  GPIO_InitStruct.Pin = GPIO_PIN_5|GPIO_PIN_4;
  GPIO_InitStruct.Mode = GPIO_MODE_AF_PP;
  GPIO_InitStruct.Pull = GPIO_NOPULL;
  GPIO_InitStruct.Speed = GPIO_SPEED_FREQ_LOW;
  GPIO_InitStruct.Alternate = GPIO_AF10_SAI4;
  HAL_GPIO_Init(GPIOE, &GPIO_InitStruct);

}

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


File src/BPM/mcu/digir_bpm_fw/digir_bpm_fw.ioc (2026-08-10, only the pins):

Mcu.UserName=STM32H745XIHx
PA1.GPIO_Label=MII_RX_CLK
PA1.Signal=ETH_RX_CLK
PA10.GPIO_Label=USB_OTG_FS2_ID
PA10.Signal=GPIO_Input
PA11.GPIO_Label=USB_OTG_FS2_N
PA11.Signal=USB_OTG_FS_DM
PA12.GPIO_Label=USB_OTG_FS2_P
PA12.Signal=USB_OTG_FS_DP
PA2.GPIO_Label=MII_MDIO
PA2.Signal=ETH_MDIO
PA7.GPIO_Label=MII_RX_DV
PA7.Signal=ETH_RX_DV
PA9.GPIO_Label=VBUS_FS2
PA9.Signal=USB_OTG_FS_VBUS
PB0.GPIO_Label=MII_RXD2
PB0.Signal=ETH_RXD2
PB1.GPIO_Label=MII_RXD3
PB1.Signal=ETH_RXD3
PB10.GPIO_Label=VCP_TX
PB10.Signal=USART3_TX
PB11.GPIO_Label=VCP_RX
PB11.Signal=USART3_RX
PB12.GPIO_Label=LCD_RST
PB12.Signal=GPIO_Output
PB13.GPIO_Label=FDCAN2_TX
PB13.Signal=FDCAN2_TX
PB14.Signal=USART1_TX
PB15.Signal=SPI2_MOSI
PB5.GPIO_Label=FDCAN2_RX
PB5.Signal=FDCAN2_RX
PB6.Signal=QUADSPI_BK1_NCS
PB7.Signal=USART1_RX
PB8.GPIO_Label=SDIO1_D4
PB8.Signal=SDMMC1_D4
PB9.GPIO_Label=SDIO1_D5
PB9.Signal=SDMMC1_D5
PC1.GPIO_Label=MII_MDC
PC1.Signal=ETH_MDC
PC10.GPIO_Label=SDIO1_D2
PC10.Signal=SDMMC1_D2
PC11.GPIO_Label=SDIO1_D3
PC11.Signal=SDMMC1_D3
PC12.GPIO_Label=SDIO1_CK
PC12.Signal=SDMMC1_CK
PC13.GPIO_Label=B1 [Blue PushButton]
PC13.Signal=GPIO_Input
PC2.GPIO_Label=MII_TXD2
PC2.Signal=ETH_TXD2
PC3.GPIO_Label=MII_TX_CLK
PC3.Signal=ETH_TX_CLK
PC4.GPIO_Label=MII_RXD0
PC4.Signal=ETH_RXD0
PC5.GPIO_Label=MII_RXD1
PC5.Signal=ETH_RXD1
PC6.GPIO_Label=SDIO1_D6
PC6.Signal=SDMMC1_D6
PC7.GPIO_Label=SDIO1_D7
PC7.Signal=SDMMC1_D7
PC8.GPIO_Label=SDIO1_D0
PC8.Signal=SDMMC1_D0
PC9.GPIO_Label=SDIO1_D1
PC9.Signal=SDMMC1_D1
PD0.Signal=FMC_D2_DA2
PD1.Signal=FMC_D3_DA3
PD10.Signal=FMC_D15_DA15
PD11.Signal=QUADSPI_BK1_IO0
PD14.Signal=FMC_D0_DA0
PD15.Signal=FMC_D1_DA1
PD2.GPIO_Label=SDIO1_CMD
PD2.Signal=SDMMC1_CMD
PD3.Signal=SPI2_SCK
PD7.GPIO_Label=LCD_DISP
PD7.Signal=GPIO_Input
PD8.Signal=FMC_D13_DA13
PD9.Signal=FMC_D14_DA14
PE0.Signal=FMC_NBL0
PE1.Signal=FMC_NBL1
PE10.Signal=FMC_D7_DA7
PE11.Signal=FMC_D8_DA8
PE12.Signal=FMC_D9_DA9
PE13.Signal=FMC_D10_DA10
PE14.Signal=FMC_D11_DA11
PE15.Signal=FMC_D12_DA12
PE2.GPIO_Label=MII_TXD3
PE2.Signal=ETH_TXD3
PE4.Signal=SAI4_D2
PE5.Signal=SAI4_CK2
PE7.Signal=FMC_D4_DA4
PE8.Signal=FMC_D5_DA5
PE9.Signal=FMC_D6_DA6
PF0.Signal=FMC_A0
PF1.Signal=FMC_A1
PF10.Signal=QUADSPI_CLK
PF11.Signal=FMC_SDNRAS
PF12.Signal=FMC_A6
PF13.Signal=FMC_A7
PF14.Signal=FMC_A8
PF15.Signal=FMC_A9
PF2.Signal=FMC_A2
PF3.Signal=FMC_A3
PF4.Signal=FMC_A4
PF5.Signal=FMC_A5
PF6.Signal=QUADSPI_BK1_IO3
PF7.Signal=QUADSPI_BK1_IO2
PF9.Signal=QUADSPI_BK1_IO1
PG0.Signal=FMC_A10
PG1.Signal=FMC_A11
PG10.Signal=SAI2_SD_B
PG11.GPIO_Label=MII_TX_EN
PG11.Signal=ETH_TX_EN
PG12.GPIO_Label=MII_TXD1
PG12.Signal=ETH_TXD1
PG13.GPIO_Label=MII_TXD0
PG13.Signal=ETH_TXD0
PG15.Signal=FMC_SDNCAS
PG2.GPIO_Label=LCD_INT
PG2.Signal=GPXTI2
PG4.Signal=FMC_A14_BA0
PG5.Signal=FMC_A15_BA1
PG8.Signal=FMC_SDCLK
PH11.GPIO_Label=USB_OTG_FS2_OverCurrent
PH11.Signal=GPXTI11
PH13.GPIO_Label=FDCAN1_TX
PH13.Signal=FDCAN1_TX
PH14.GPIO_Label=FDCAN2_RX
PH14.Signal=FDCAN1_RX
PH2.GPIO_Label=MII_CRS
PH2.Signal=ETH_CRS
PH3.GPIO_Label=MII_COL
PH3.Signal=ETH_COL
PH5.Signal=FMC_SDNWE
PH6.Signal=FMC_SDNE1
PH7.Signal=FMC_SDCKE1
PH9.Signal=LTDC_R3
PI0.Signal=LTDC_G5
PI1.Signal=LTDC_G6
PI10.GPIO_Label=MII_RX_ER
PI10.Signal=ETH_RX_ER
PI12.Signal=LTDC_HSYNC
PI13.GPIO_Label=LD2 [Green Led]
PI13.Signal=GPIO_Output
PI14.Signal=LTDC_CLK
PI15.Signal=LTDC_R0
PI2.Signal=SPI2_MISO
PI4.Signal=SAI2_MCLK_A
PI5.Signal=SAI2_SCK_A
PI6.Signal=SAI2_SD_A
PI7.Signal=SAI2_FS_A
PI9.Signal=LTDC_VSYNC
PJ0.Signal=LTDC_R1
PJ1.Signal=LTDC_R2
PJ10.Signal=LTDC_G3
PJ11.Signal=LTDC_G4
PJ12.Signal=LTDC_B0
PJ13.Signal=LTDC_B1
PJ14.Signal=LTDC_B2
PJ15.GPIO_Label=LCD_DISP
PJ15.Signal=LTDC_B3
PJ2.GPIO_Label=LD1 [Red Led]
PJ2.Signal=GPIO_Output
PJ3.Signal=LTDC_R4
PJ4.Signal=LTDC_R5
PJ5.Signal=LTDC_R6
PJ6.Signal=LTDC_R7
PJ7.Signal=LTDC_G0
PJ8.Signal=LTDC_G1
PJ9.Signal=LTDC_G2
PK0.GPIO_Label=LCD_BL
PK0.Signal=GPIO_Input
PK2.Signal=LTDC_G7
PK3.Signal=LTDC_B4
PK4.Signal=LTDC_B5
PK5.Signal=LTDC_B6
PK6.Signal=LTDC_B7
PK7.Signal=LTDC_DE

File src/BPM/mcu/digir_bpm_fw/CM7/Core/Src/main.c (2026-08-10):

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
/* Includes ------------------------------------------------------------------*/
#include "main.h"

/* USER CODE BEGIN Includes */

#include "log.h"
#include "gnss_uart.h"
#include "nmea_parser.h"
#include "task_manager.h"
#include "global_state.h"
#include "spi_ctl.h"

/* USER CODE END Includes */

/* USER CODE BEGIN PD */

/* DUAL_CORE_BOOT_SYNC_SEQUENCE: Define for dual core boot synchronization    */
/*                             demonstration code based on hardware semaphore */
/* This define is present in both CM7/CM4 projects                            */
/* To comment when developping/debugging on a single core                     */
#define DUAL_CORE_BOOT_SYNC_SEQUENCE

#if defined(DUAL_CORE_BOOT_SYNC_SEQUENCE)
#ifndef HSEM_ID_0
#define HSEM_ID_0 (0U) /* HW semaphore 0*/
#endif
#endif /* DUAL_CORE_BOOT_SYNC_SEQUENCE */

/* USER CODE END PD */


SPI_HandleTypeDef hspi2;

UART_HandleTypeDef huart1;
UART_HandleTypeDef huart3;

void SystemClock_Config(void);
static void MPU_Config(void);
static void MX_GPIO_Init(void);
static void MX_USART1_UART_Init(void);
static void MX_USART3_UART_Init(void);
static void MX_SPI2_Init(void);
/**
  * @brief  The application entry point.
  * @retval int
  */
int main(void)
{

/* USER CODE BEGIN Boot_Mode_Sequence_0 */
#if defined(DUAL_CORE_BOOT_SYNC_SEQUENCE)
  int32_t timeout;
#endif /* DUAL_CORE_BOOT_SYNC_SEQUENCE */
/* USER CODE END Boot_Mode_Sequence_0 */

  /* MPU Configuration--------------------------------------------------------*/
  MPU_Config();

/* USER CODE BEGIN Boot_Mode_Sequence_1 */
#if defined(DUAL_CORE_BOOT_SYNC_SEQUENCE)
  /* Wait until CPU2 boots and enters in stop mode or timeout*/
  timeout = 0xFFFF;
  while((__HAL_RCC_GET_FLAG(RCC_FLAG_D2CKRDY) != RESET) && (timeout-- > 0));
  if ( timeout < 0 )
  {
  Error_Handler();
  }
#endif /* DUAL_CORE_BOOT_SYNC_SEQUENCE */
/* USER CODE END Boot_Mode_Sequence_1 */
  /* MCU Configuration--------------------------------------------------------*/

  /* Reset of all peripherals, Initializes the Flash interface and the Systick. */
  HAL_Init();

  /* Configure the system clock */
  SystemClock_Config();
/* USER CODE BEGIN Boot_Mode_Sequence_2 */
#if defined(DUAL_CORE_BOOT_SYNC_SEQUENCE)
/* When system initialization is finished, Cortex-M7 will release Cortex-M4 by means of
HSEM notification */
/*HW semaphore Clock enable*/
__HAL_RCC_HSEM_CLK_ENABLE();
/*Take HSEM */
HAL_HSEM_FastTake(HSEM_ID_0);
/*Release HSEM in order to notify the CPU2(CM4)*/
HAL_HSEM_Release(HSEM_ID_0,0);
/* wait until CPU2 wakes up from stop mode */
timeout = 0xFFFF;
while((__HAL_RCC_GET_FLAG(RCC_FLAG_D2CKRDY) == RESET) && (timeout-- > 0));
if ( timeout < 0 )
{
Error_Handler();
}
#endif /* DUAL_CORE_BOOT_SYNC_SEQUENCE */
/* USER CODE END Boot_Mode_Sequence_2 */

  /* Initialize all configured peripherals */
  MX_GPIO_Init();
  MX_USART1_UART_Init();
  MX_USART3_UART_Init();
  MX_SPI2_Init();
  /* USER CODE BEGIN 2 */

  global_state_init(get_global_state());
  gnss_uart_reader_init(get_gnss_uart_reader(), &huart1, GNSS_INPUT_FORMAT_NMEA);

  spi_controller_t spi2_control;
  spi_controller_init(&spi2_control, &hspi2, GPIOB, GPIO_PIN_4);

  /* USER CODE END 2 */

  /* Infinite loop */
  /* USER CODE BEGIN WHILE */
  set_global_log_handle(&huart3);
  task_manager_init(get_global_task_manager());

  log_info("Starting up DigiR...");

  int cnt = 0;
  while (1)
  {
    cnt++;
    task_manager_run(get_global_task_manager());
    if (cnt % 100 == 0)
    {
      uint8_t bytes[4];
      bytes[0] = 'D';
      bytes[1] = 'E';
      bytes[2] = 'A';
      bytes[3] = 'D';
      spi_controller_tx(&spi2_control, 4, bytes);
    }
    /* USER CODE END WHILE */

    /* USER CODE BEGIN 3 */
  }

  /* USER CODE END 3 */
}

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
 /* MPU Configuration */

void MPU_Config(void)
{
  MPU_Region_InitTypeDef MPU_InitStruct = {0};

  /* Disables the MPU */
  HAL_MPU_Disable();

  /** Initializes and configures the Region and the memory to be protected
  */
  MPU_InitStruct.Enable = MPU_REGION_ENABLE;
  MPU_InitStruct.Number = MPU_REGION_NUMBER0;
  MPU_InitStruct.BaseAddress = 0x0;
  MPU_InitStruct.Size = MPU_REGION_SIZE_4GB;
  MPU_InitStruct.SubRegionDisable = 0x87;
  MPU_InitStruct.TypeExtField = MPU_TEX_LEVEL0;
  MPU_InitStruct.AccessPermission = MPU_REGION_NO_ACCESS;
  MPU_InitStruct.DisableExec = MPU_INSTRUCTION_ACCESS_DISABLE;
  MPU_InitStruct.IsShareable = MPU_ACCESS_SHAREABLE;
  MPU_InitStruct.IsCacheable = MPU_ACCESS_NOT_CACHEABLE;
  MPU_InitStruct.IsBufferable = MPU_ACCESS_NOT_BUFFERABLE;

  HAL_MPU_ConfigRegion(&MPU_InitStruct);
  /* Enables the MPU */
  HAL_MPU_Enable(MPU_PRIVILEGED_DEFAULT);

}

/**
  * @brief  This function is executed in case of error occurrence.
  * @retval None
  */
void Error_Handler(void)
{
  /* USER CODE BEGIN Error_Handler_Debug */
  /* User can add his own implementation to report the HAL error return state */
  __disable_irq();
  while (1)
  {
  }
  /* USER CODE END Error_Handler_Debug */
}
#ifdef USE_FULL_ASSERT
/**
  * @brief  Reports the name of the source file and the source line number
  *         where the assert_param error has occurred.
  * @param  file: pointer to the source file name
  * @param  line: assert_param error line source number
  * @retval None
  */
void assert_failed(uint8_t *file, uint32_t line)
{
  /* USER CODE BEGIN 6 */
  /* User can add his own implementation to report the file name and line number,
     ex: printf("Wrong parameters value: file %s on line %d\r\n", file, line) */
  /* USER CODE END 6 */
}
#endif /* USE_FULL_ASSERT */

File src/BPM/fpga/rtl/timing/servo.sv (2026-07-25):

//#################################################################################################
//  DIGIR BPM TIMING SERVO IP
//
//  VERSION 0.1
//#################################################################################################

// This module defines the controller which takes in the fractional phase error of the reference
// clock against the GPNSS PPS, and generates an output control signal to discipline the VCTCXO.
// The control signal must be output at the correct bit width for the BPM internal DAC.

// For the loop constants, we currently use a power of two model to allow shifting instead of
// hardware multiplier usage. Changing to multiplication could enable additional precision, but
// multipliers are currently being reserved for DSP usage. If the performance proves to be too poor
// on the hardware, we can reconsider.

// Note that the sign convention for the phase error and control signal may need to be adjusted for
// the real oscillator. The phase error is defined as oscillator phase - GNSS phase, so if the clk
// is fast, we will see a positive sign error. Currently, a positive sign error produces a negative
// control signal. A parameter for this polarity is included, called POLARITY. It is defined so
// that if high, the control signal will have the opposite sign of the phase error.

// When tuning, note the units at play here. Phase error is expressed in ticks of the oscillator.
// The control output units depend on characteristics of both the DAC and the oscillator. The
// unit of the proportional control constant is DAC codes / clk tick, and the unit of the integral
// constant is thus DAC codes / clk tick / second. The shift parameters in the module allow tuning
// of these constants to produce appropriate voltage per error level dependent on the
// characteristics of the hardware. For bench testing it may later become useful to be able to
// write in different control constants from the MCU, so the shifts may later become input signals.

//#################################################################################################
//  CHANGE LOG
//#################################################################################################

// 7/25/26  Edward Speer  Initial revision

//#################################################################################################
//  MODULE DEFINITION
//#################################################################################################

module servo #(
    parameter int unsigned REF_CLK_HZ  = 100000000,
    parameter int unsigned PHASE_WIDTH = (REF_CLK_HZ > 1) ? $clog2(REF_CLK_HZ) : 1,
    parameter int unsigned DAC_WIDTH   = 12,
    parameter int unsigned ACC_WIDTH   = 48, // Width of internal accumulator
    parameter int unsigned FRAC_WIDTH  = 16, // Width of fixed point fractional part
    parameter int unsigned KP_SHIFT    = 8,
    parameter int unsigned KI_SHIFT    = 16,
    parameter int unsigned POLARITY    = 1
)(
    input  logic                          reset,
    input  logic                          clk,

    input  logic signed [PHASE_WIDTH-1:0] phase_err,        // From phase err capture block
    input  logic                          phase_err_valid,

    input  logic [DAC_WIDTH-1:0]          nominal_dac_code, // DAC code at center of tuning range
    input  logic [DAC_WIDTH-1:0]          min_dac_code,     // Minimum allowable control output
    input  logic [DAC_WIDTH-1:0]          max_dac_code,     // Maximum allowable control output

    output logic [DAC_WIDTH-1:0]          dac_code,         // Output control signal
    output logic                          dac_code_valid,

    output logic [ACC_WIDTH-1:0]          integrator_state, // Exposed for tuning and debug
    output logic                          output_saturated  // Desired control is outside bounds
);
    logic [ACC_WIDTH-1:0] phase_err_extended;
    logic [ACC_WIDTH-1:0] phase_err_scaled;
    logic [ACC_WIDTH-1:0] p_term;
    logic [ACC_WIDTH-1:0] i_term;
    logic [ACC_WIDTH-1:0] dac_nominal_scaled;
    logic [ACC_WIDTH-1:0] dac_min_scaled;
    logic [ACC_WIDTH-1:0] dac_max_scaled;
    logic [ACC_WIDTH-1:0] integrator_proposed;
    logic [ACC_WIDTH-1:0] output_proposed;
    logic [ACC_WIDTH-1:0] integrator_selected;
    logic [ACC_WIDTH-1:0] output_selected;
    logic [ACC_WIDTH-1:0] output_limited;

    logic integrator_update_allowed; // Do not update integrator state when output saturated

    always_comb begin
        // Default control state
        output_saturated          = 1'b0;
        integrator_update_allowed = 1'b1;

        // Convert input phase error into internal fixed point representation
        phase_err_extended = {{(ACC_WIDTH-PHASE_WIDTH){phase_err[PHASE_WIDTH-1]}}, phase_err};
        phase_err_scaled   = phase_err_extended <<< FRAC_WIDTH;

        // Compute PI terms
        p_term = phase_err_scaled >>> KP_SHIFT;
        i_term = phase_err_scaled >>> KI_SHIFT;

        // Express DAC parameters in internal fixed point representation
        dac_nominal_scaled = $signed({1'b0, nominal_dac_code}) <<< FRAC_WIDTH;
        dac_min_scaled     = $signed({1'b0, min_dac_code}) <<< FRAC_WIDTH;
        dac_max_scaled     = $signed({1'b0, max_dac_code}) <<< FRAC_WIDTH;

        // Compute the proposed new integrator and control output
        integrator_proposed = i_term + integrator_state;
        if (POLARITY) begin
            output_proposed = nominal_scaled - integrator_proposed - p_term;
        end
        else begin
            output_proposed = nominal_scaled + integrator_proposed + p_term;
        end

        // Prevent integrator windup by capping at saturation
        if ((output_proposed > dac_max_scaled) && (i_term > 0)) begin
            integrator_update_allowed = 1'b0;
        end
        if ((output_proposed < dac_min_scaled) && (i_term < 0)) begin
            integrator_update_allowed = 1'b0;
        end
        if (integrator_update_allowed) begin
            integrator_selected = integrator_proposed;
        end
        else begin
            integrator_selected = integrator_state;
        end

        // Recalculate the output using the selected integrator
        if (POLARITY) begin
            output_selected = nominal_scaled - integrator_selected - p_term;
        end
        else begin
            output_selected = nominal_scaled + integrator_selected + p_term;
        end
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

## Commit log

2026-07-25 Implement time servo
2026-07-28 Add STM32 project
2026-07-29 UART1 receiving NMEA
2026-08-15 Initial SPI RTL
2026-08-21 Clock tree evb PCB design
    [clk_pt.kicad_pcb, clk_pt.kicad_sch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]

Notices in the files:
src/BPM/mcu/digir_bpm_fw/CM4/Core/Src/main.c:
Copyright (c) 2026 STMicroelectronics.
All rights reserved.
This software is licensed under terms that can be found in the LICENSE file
